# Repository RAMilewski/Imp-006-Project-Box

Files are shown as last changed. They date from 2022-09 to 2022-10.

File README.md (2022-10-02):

# Imp-006-Project-Box
Modular box for Electric Imp 006 breakout board and add-ons.

The Imp006 breakout board offers world-class security and ubiquitous connectivity, including cellular data starting at $3 per month that can be turned off and on again to avoid connectivity charges.  It has GPS, Glonass, Galileo, Beidu/Compass, & QZSS positioning, as well as dual-band WiFi, and BLE networking.  i2c, Mikro Bus and 8 UART connections are available as well as a GPIO connector. See https://www.electricimp.com/imp006-breakout/ for full documentation.

There are two different box lids available.  The two-piece lid that involves a color change, or a one-piece blank lid. All of the provided STLs print without supports. Proper rendering of the logo panel requires Comfortaa Bold a free Google typeface, and two Avenir fonts, Avenir Black Oblique and Next Condensed Heavy, both of which are available from multiple free online sources. Avenir Next Condensed Heavy is also used for the GNSS antenna holder.

The box design acommodates the use of “mezzanine” expansion layers that stack between the box and the lid.  A mezzanine layer with prototyping breadboards is forthcoming.

The OpenSCAD file requires the BOSL2 library, see https://github.com/revarbat/BOSL2. Full BOSL2 documentiation with copius examples is at https://github.com/revarbat/BOSL2/wiki. 

The OpenSCAD file can render all of the STLs with the Customizer allowing custom tweaks.

The Antenna Plate STL is included to allow mounting the adhesive-backed cellular antenna, although use of the part is optional.  You can simply slip the antenna with the adhesive backing paper attached into the antenna slot in the box.  I don't recommend sticking the antenna to the box as that makes moving the antenna to a different (improved?) box in the future more difficult.

 Version 2.4 Update

 Raised the pcb to accomodate the Twilio recommended 3.7v 2000ma battery (Adafruit product ID 2011).  See the Electric Imp documentation for jumper setting details to enable the on-board battery charger. IMPORTANT: Before substituting similar batteries from other sources, double check the polarity at the battery's JST connector.

 Made minor adjustments to the position of the grove and USB connector holes improve the fit of the board.

 Repositioned the GNSS antenna to clear Mikro Click sensor boards. See https://www.mikroe.com/click for more than a thousand Click boards, including 450 sensor boards.

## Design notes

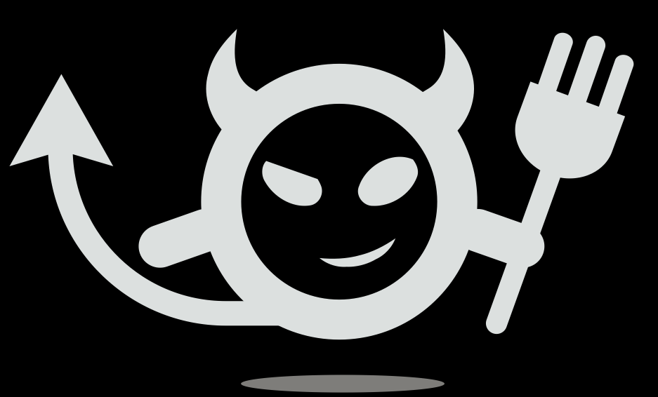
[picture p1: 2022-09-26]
Images/The Dude.png

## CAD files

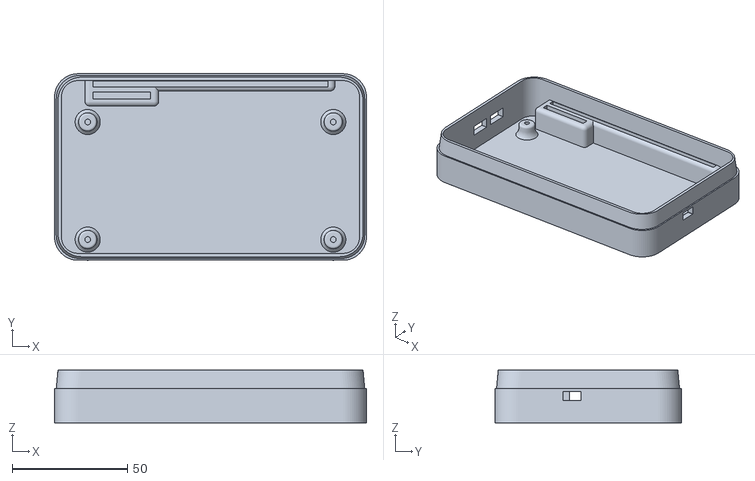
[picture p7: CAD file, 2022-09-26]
006 STLs/2.3 STLs/box.stl
135.5 x 81.0 x 23.0

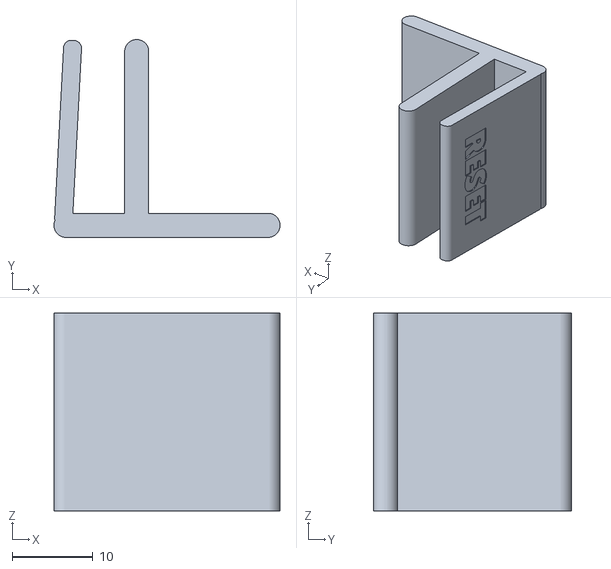
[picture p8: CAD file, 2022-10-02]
006 STLs/2.4 STLs/gnss_2.4.stl
28.0 x 24.5 x 24.5

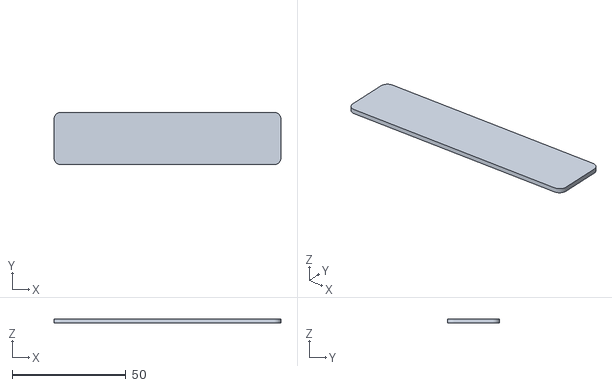
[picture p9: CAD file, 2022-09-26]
006 STLs/2.3 STLs/antenna_plate.stl
100.0 x 23.0 x 1.75

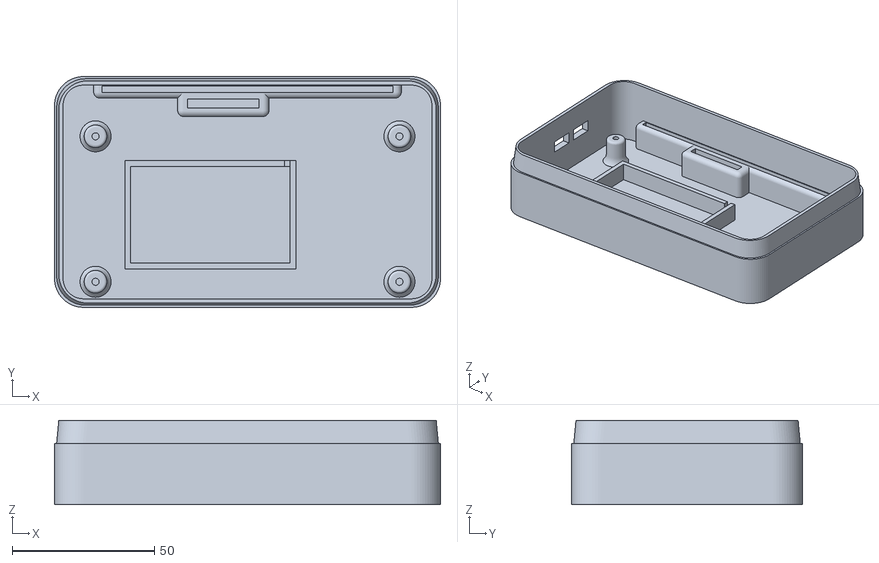
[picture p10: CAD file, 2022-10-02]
006 STLs/2.4 STLs/box_2.4.stl
135.5 x 81.0 x 29.5

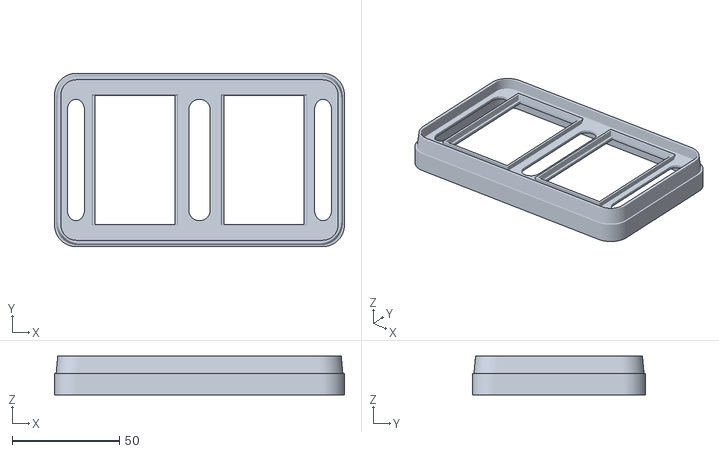
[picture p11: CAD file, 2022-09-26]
006 STLs/2.3 STLs/breadboard.stl
135.5 x 81.0 x 18.0

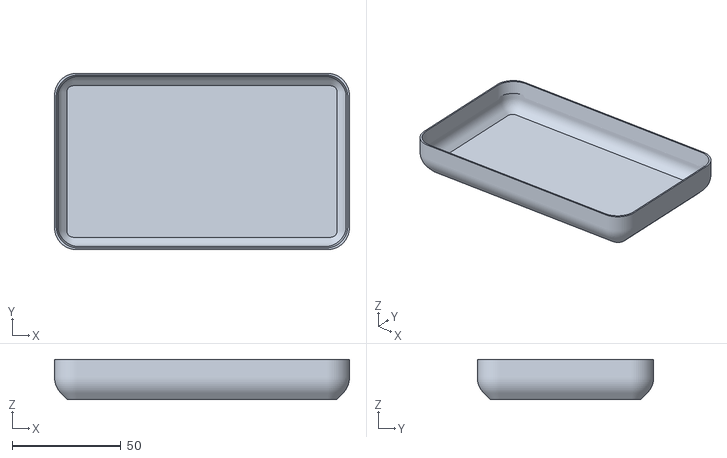
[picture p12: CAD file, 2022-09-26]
006 STLs/2.4 STLs/lid_blank_2.4.stl
135.5 x 81.0 x 18.5

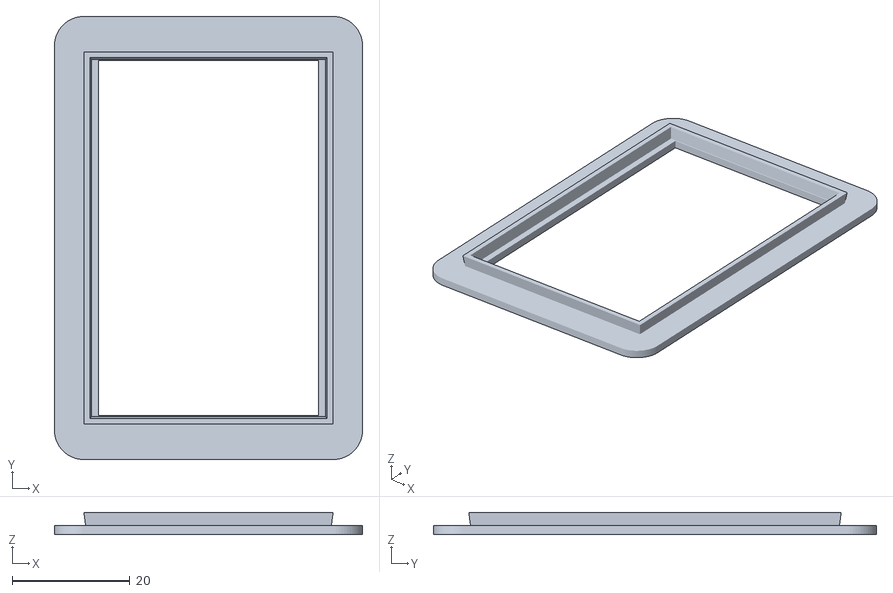
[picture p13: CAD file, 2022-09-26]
006 STLs/2.3 STLs/breadboard_test.stl
52.3 x 75.2 x 3.75

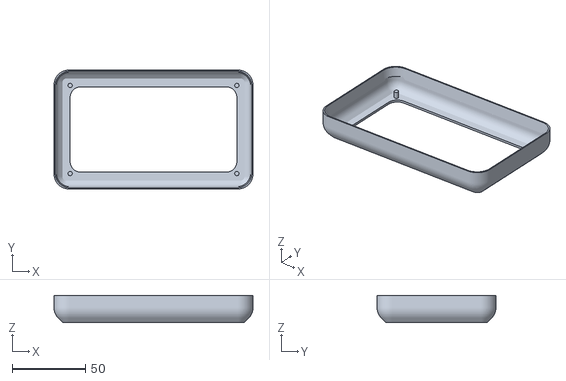
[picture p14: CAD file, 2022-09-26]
006 STLs/2.4 STLs/lid_logo_2.4.stl
135.5 x 81.0 x 18.5

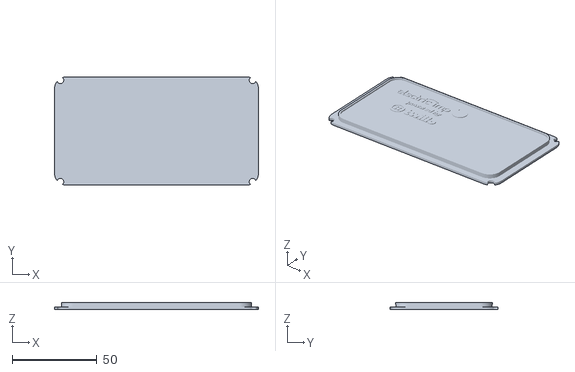
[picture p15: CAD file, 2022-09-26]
006 STLs/2.3 STLs/logo.stl
120.5 x 64.0 x 4.00

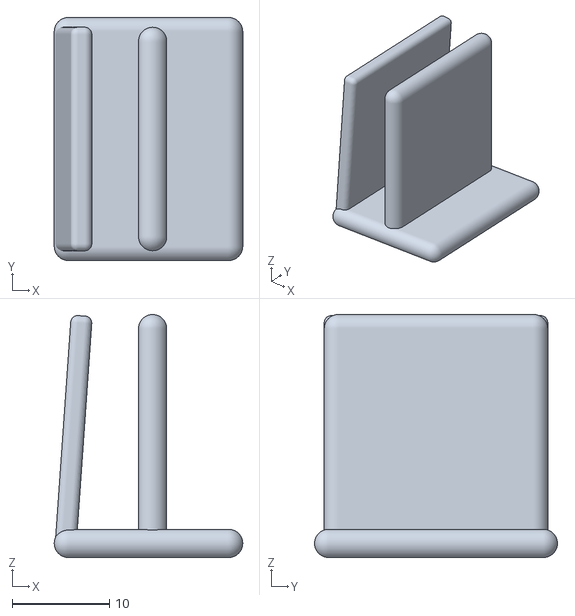
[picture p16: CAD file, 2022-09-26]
006 STLs/2.3 STLs/gnss.stl
19.4 x 25.0 x 25.0

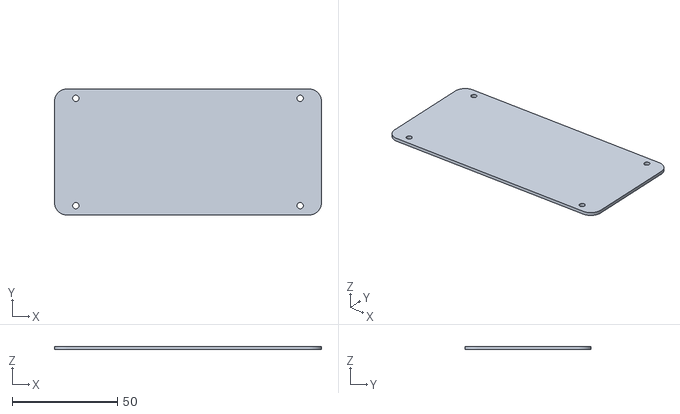
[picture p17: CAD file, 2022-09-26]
006 STLs/2.3 STLs/pcb.stl
127.0 x 60.0 x 1.60

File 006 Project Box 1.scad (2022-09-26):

/*#################################################################################*\
   006 Project Box 1.scad
	-----------------------------------------------------------------------------

	Developed by:			Richard A. Milewski
	Description:            Project Box for Electric Imp 006 Breakout Board
   	
	Version:                1.0
	Creation Date:          30 July 2022
	Modification Date:      
	Email:                  richard+scad@milewski.org
	Copyright				©2022 by Richard A. Milewski
    License - CC-BY-NC      https://creativecommons.org/licenses/by-nc/3.0/ 

\*#################################################################################*/


/*#################################################################################*\
    
    Notes

	Measurements labeled <NEC> are from the New Age Enclosures PDF spec sheet.
	Dimensions labelens <Measured> are from an Imp 006 Breakout Board rev 4.0.
    The Origin of the coördinates is the XY center of the board.
\*#################################################################################*/


/*#################################################################################*\
    
    CONFIGURATION

\*#################################################################################*/
include <BOSL2/std.scad>

// The part you wish to print
part = "top";		//	[box, top, logo, antenna, GNSS, pallet, test]      


// Wall hole selectors	
use_usb = true;		// [true, false]	
use_grove = true;	// [true, false]	

// Logo on top?
use_logo = true;	// true prints a 2 piece top, false prints a single piece top

// Set to false before rendering stl.
show_pcb = false;      // [true, false]

module hidevars () {}  	// variables below hidden from Customizer


$fn = 64;


pcb      = [127, 60, 1.6];						            // <Measured>
pcb2     = [2.5 * INCH * 2, 1.28 * INCH * 2, 0.062 * INCH]; // <NEC> Mythical PCB prototype.
offset   = [0,-12,5];	
mount_hole_dwg = [-.120 * INCH, undef, 0.062 * INCH];		// Mounting hole from <NEC> PDF. 	
mount   = [2.1 * INCH, 1.005 * INCH];			            // Mounting hole positions from <NEC> PCB

mount_spacing = [mount.x * 2, mount.y * 2];
mount_stud = [6, undef, offset.z];
mount_hole = [3, undef, 6];

corner  = 0.4 * INCH; 							
icorner = corner * 0.6;		// A judgment call, seems to look ok.

box_wall = 3;
box = [pcb.x + abs(offset.x) + 3 * box_wall, pcb.y + abs(offset.y) + 3 * box_wall, 27];
wall_position = [box.x/2-box_wall/2, box.y/2-box_wall/2];
pcb_edge = [offset.x + pcb.x/2, offset.y + pcb.y/2, offset.z + pcb.z + box_wall];

top = [box.x, box.y, 8];
top_pin = [5, undef, box_wall + 5];
top_pin_spacing = [top.x - 20, top.y - 20];

deck = [box.x - 3 * box_wall, box.y - 3 * box_wall, 2];
logo_cutout = [box.x-25, box.y-25, box_wall];
logo_border = 2;

stacker_taper = 0.75 * box_wall;
stacker_edge = 0.5;
stacker = [undef, undef, 5];	// Height of the mating surface atop the box.

antenna_plate = [100, 23, 1.75];
antenna_mount = [108, 6, antenna_plate.y*0.5];
antenna_slot  = [102, 3, antenna_mount.z+1];
antenna_mount_position = [0, wall_position.y-antenna_mount.y/2, box_wall];
antenna_slot_position  = [0, box.y/2 - 1.5 * box_wall, box_wall];

gnss_mount = [32, 11, antenna_mount.z];
gnss_slot = [25, 3, antenna_mount.z+1];
gnss_slot_position = [-antenna_slot.x/2 + gnss_slot.x/2, antenna_slot_position.y - 5, box_wall];
gnss_mount_position = [-antenna_slot.x/2 + gnss_slot.x/2,wall_position.y-gnss_mount.y/2,box_wall];


// Holes in the box walls -- Fixed numbers are <Measured>

grove 	  		= [2*box_wall, 10, 5];
grove_spacing	=  grove.y + 3;
grove_position1	= [-wall_position.x - box_wall/2, -7.5 + offset.y , pcb_edge.z];
grove_position2	= [grove_position1.x, grove_position1.y + grove_spacing, grove_position1.z];
led_window	  	= [box_wall * 0.75, 4, 4]; 
led_window_position	= [wall_position.x - box_wall/2, 3.4 + offset.y, pcb_edge.z];
usb 	  		= [2*box_wall, 8, 4];
usb_position	= [wall_position.x - box_wall/2, -10 + offset.y,  pcb_edge.z];

/*#################################################################################*\
    
    Main

\*#################################################################################*/

if (part == "antenna") 	antenna();	// Mounting plate for antenna.
if (part == "box") 		box();		// Box Bottom.
if (part == "top") 	{	*top();		// Top with Logo Cutout
				up(15) logo(); }

// Related objects
if (part == "pallet") 	pallet();	// Temporary desktop platform for the breakout board.

// Test Prints
// Clipped parts of the box to test wall hole locations 
if (part == "grove_end") 	test_1("grove");		// Grove Connector Partial End Piece
if (part == "usb_end") 		test_1("usb");	// USB Connector Partial End Piece

// Utility test choice - change the function below to execute temporary modules
if (part == "test") 	back_half(s=200) logo();	// Temp Misc Tests

/*#################################################################################*\
    
	rounding = iround, edges = "Z", anchor = BOT;
    Modules

\*#################################################################################*/

module box() {
	color("slategray")   base();
	color("goldenrod")   antenna_mounts();
	color("yellow")      walls();
	color("lime")        stud_set();
	color("deepskyblue") dummy_pcb();
	color("magenta")     up(box.z) stacker();
}
	

module base () {	//the bottom of the box 
	cuboid ([box.x, box.y, box_wall], 
	rounding = corner, edges = "Z", anchor = BOT); 
}
module antenna_mounts(){
	difference() {
		union() {
			move(antenna_mount_position)
				cuboid(antenna_mount, rounding = 2, edges = [TOP,FRONT], except = [BOT,BACK], anchor = BOT); 
			move(gnss_mount_position) 
				cuboid(gnss_mount, rounding = 2, edges = [TOP,FRONT], except = [BOT,BACK], anchor = BOT); 	
		}
		union() {
			move(antenna_slot_position)
				cuboid(antenna_slot, anchor = BOT);
			move(gnss_slot_position)
			cuboid(gnss_slot, anchor = BOT);
		}
	}
}

module walls() {
	//difference() {
		rect_tube (size = [box.x, box.y], wall = box_wall, h = box.z, 
			rounding = corner, irounding = icorner, anchor = BOT);
		union() {
			move(led_window_position) color("blue") cuboid(led_window, rounding = 1, edges = "X", anchor = BOT);
			if (use_grove) {   
				move(grove_position1)  cuboid(grove, anchor = BOT);
				move(grove_position2)  cuboid(grove, anchor = BOT);
			}
			if (use_usb) move(usb_position) color("red") cuboid(usb, rounding = 0.2, anchor = BOT);
		//}
	}
}

module stud() {   // A single mounting stud.
	difference() {
			cyl(h = mount_stud.z, d = mount_stud.x, anchor = BOT);	
			down(box_wall/2) cyl(h = mount_stud.z + mount_hole.z, d = mount_hole.x, anchor = BOT);
	}
}

module stud_set() { 
	move(offset/2)
	grid2d(size = mount_spacing, spacing = mount_spacing) stud(); 
	}

module dummy_pcb() { 
	if (show_pcb) {
		move([offset.x/2, offset.y/2, offset.z * 1.5]) {  
			difference () { 
				cuboid(pcb, rounding = 6, edges = "Z", anchor = BOT); 
				grid2d(size = mount_spacing, spacing = mount_spacing) cyl(h = mount_hole.z, d = mount_hole.x);
			}
		}
	}
}

module stacker() {	// Top iterface ring to stack box 
					// yrot(180) and use as a mask for bottom interfaces 		

		A = [box.x - stacker_edge, box.y - stacker_edge];
		B = [box.x - stacker_taper - stacker_edge, box.y - stacker_taper - stacker_edge];
		C = [box.x - 2 * box_wall, box.y - 2 * box_wall];
		rect_tube ( size1 = A, size2 = B, isize = C,
			h=stacker.z, rounding = corner, irounding = icorner);
}

module top() {
	if (logo) {
		logo_deck();
	} else {
		plain_deck();
	}
	top_walls ();
}

module plain_deck () {
	cuboid ([box.x, box.y, deck.z], 	
		rounding = corner, edges = "Z", anchor = BOT);
}

module logo_deck  () {		
	difference () {
		cuboid ([box.x, box.y, deck.z], 	
			rounding = corner, edges = "Z", anchor = BOT);	
		cuboid ([logo_cutout], 	
			rounding = corner, edges = "Z", anchor = BOT); 
	}
	grid2d(size = top_pin_spacing, spacing = top_pin_spacing) 
	color("red") cyl(h = top_pin.z, d = top_pin.x, anchor = BOT); 
}


module top_walls() {
	difference() {
		rect_tube (size = [top.x, top.y], wall = box_wall, h = top.z, 
			rounding = corner, irounding = icorner, anchor = BOT);
		up (top.z) yrot (180) stacker();
	}
}

module logo() {
	difference() {
		cuboid( deck, rounding = icorner, edges = "Z", anchor = BOT);
		grid2d(size = top_pin_spacing, spacing = top_pin_spacing) 
			color("red") cyl(h = deck.z + 1, d = top_pin.x + 1, anchor = BOT); 
	}
	up(1) cuboid (logo_cutout, 	
			rounding = icorner, edges = "Z", anchor = BOT);
	up(4) color("skyblue") rect_tube (size = [logo_cutout.x, logo_cutout.y], h = box_wall, wall = logo_border, 	
			rounding = icorner, anchor = BOT); 
}

//Loose Parts

module antenna() { cuboid (antenna_plate, edges = "Z", rounding = 3); }   // Cellular antenna plate

module lens() { cuboid(lens, anchor = LEFT); }
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

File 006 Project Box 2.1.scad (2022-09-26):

/*#################################################################################*\
   006 Project Box.scad
	-----------------------------------------------------------------------------
	Developed by:			Richard A. Milewski
	Description:            Project Box for Electric Imp 006 Breakout Board
   	
	Version:                2.1
	Creation Date:          30 July 2022
	Modification Date:      24 Aug 2022
	Email:                  richard+scad@milewski.org
	Copyright				©2022 by Richard A. Milewski
    License - CC-BY-NC      https://creativecommons.org/licenses/by-nc/3.0/ 

##################################################################################\
		CONFIGURATION
#################################################################################*/

/*	Measurements labeled <NEC> are from the New Age Enclosures spec sheet pdf.
	Dimensions labeled <Measured> are from an Imp 006 Breakout Board rev 4.0.
	The Origin of the coördinate space is the XY center of the board.
	The USB connector overhangs the edge of the rev 4.0 PCB by 1.5 mm.
*/
include <BOSL2/std.scad>
include <imp006_logos.scad>


// The part you wish to print
part = "breadboard";		//	[antenna, box, gnss, lid, logo, breadboard]      


// Wall hole selectors	
use_usb = true;		// [true, false]	
use_grove = true;	// [true, false]	

// Logo on top deck?
use_logo = true;	// true prints a top with a cut-out for a logo plate, 
					// false prints a blank top

// Set to false before rendering stl.
show_pcb = false;      // [true, false]

$slop = 0.1;			// printer dependant clearance for nested parts.

module hidevars () {}  	// variables below hidden from Customizer

$fn = 64;

pcb_NEC = [2.5 * INCH * 2, 1.28 * INCH * 2, 0.062 * INCH];	// <NEC> Mythical PCB prototype.
pcb	= [127, 60, 1.6];	 						            // <Measured>

box_shift = [0,6,0];	// Move the box, but keep the board centered on the origin.
box_wall = 3;
usb_offset = use_usb ? 0 : 2; 
box = [pcb.x + 8.5 + usb_offset , pcb.y + 21, 15]; 
// Note: box.z is only the height of the lower box, 
//		 it does not include lid.z or stacker.z. 
wall_iedge = [box.x/2-box_wall/2, box.y/2-box_wall/2];
pcb_lift = 5;			// To enable mounting screws 
pcb_edge = [pcb.x/2, pcb.y/2, pcb_lift + pcb.z + box_wall];
base = [box.x, box.y, box_wall/2];

pcb_mount_hole_dwg = [-.120 * INCH, undef, 0.062 * INCH];	// Mounting hole from <NEC> PDF. 	
pcb_mount = [2.1 * INCH, 1.005 * INCH];			            // Mounting hole positions from <NEC> pdf
pcb_mount_spacing = [pcb_mount.x * 2, pcb_mount.y * 2];
pcb_mount_stud = [11, 6, pcb_lift + box_wall];
pcb_mount_hole = [2.5, undef, 6];

corner  = 0.4 * INCH; 	// radius of pcb corner  10.16mm				
icorner = corner - box_wall;		
top = [box.x, box.y, 8];
top_pin = [3, undef, box_wall + 3];
top_pin_spread = [top.x - 22, top.y - 21];
top_pin_spacing = [top_pin_spread];

stacker_taper = 0.75 * box_wall;
stacker_edge = 0.5;
stacker = [box.x, box.y, 8];	// Height of the mating surface atop the box.

curve_comp = [7,6];   	// Shrink deck to compensate for rounding curve in the lid.
logo_cutout = [box.x-23, box.y-24, box_wall];
deck = [logo_cutout.x + 8, logo_cutout.y + 7, 1];
logo_border = 2;
logo_z = 0.5;  //height of the logo in the contrastng color
logo_position = [-deck.x*0.18, deck.y*0.16, logo_cutout.z];
lid_size = [box.x, box.y, corner + stacker.z * 0.55];
lid_mask = [lid_size.x - box_wall, lid_size.y - box_wall, lid_size.z];

echo2([box-logo_cutout, logo_cutout, top_pin_spread]);

antenna_plate = [100, 23, 1.75];
antenna_mount = [108, 6, antenna_plate.y*0.5];
antenna_slot  = [102, 2.5, antenna_mount.z+1];
antenna_slot_position  = [0, box.y/2 - 1.5 * box_wall, base.z];
antenna_mount_position = [0, wall_iedge.y - antenna_mount.y/2, base.z];

gnss = [25,25,6.5];
gnss_mount = [32, 11, antenna_mount.z];
gnss_slot = [25, 3, antenna_mount.z+1];
gnss_slot_position = [-antenna_slot.x/2 + gnss_slot.x/2, antenna_slot_position.y - 5, base.z];
gnss_mount_position = [-antenna_slot.x/2 + gnss_slot.x/2,wall_iedge.y - box_wall/2 - gnss_mount.y/2, base.z];
gnss_height = 18;
gnss_cavity_wall = 1.5;

// Holes in the box walls -- Fixed numbers are <Measured>...  or guessed at.

grove 	  		= [box_wall+0.1, 10, 5];
grove_spacing	=  grove.y + 3;
grove_position1	= [-wall_iedge.x,  3 - box_shift.y, pcb_edge.z];
grove_position2	= [grove_position1.x, grove_position1.y + grove_spacing, grove_position1.z];
led_window	  	= [box_wall, 6, 5]; 
led_window_position	= [wall_iedge.x - box_wall/4, 13.4 - box_shift.y - led_window.y/2, pcb_edge.z];
usb 	  		= [box_wall+0.1, 8, 4.2];
usb_position	= [wall_iedge.x, -1 - box_shift.y,  pcb_edge.z];

// Mezzanene Parts

//for breadboard mezzanene
breadboard1 = [40.33, 70.17, 1.6];
cable_hole1 = [10,box.y * 0.7, stacker.z * 2];


/*####   Main   #################################################################*/

if (part == "box") 			box();			// Box Bottom.
if (part == "lid") 			lid();			// Top with optional cutout for logo plate.
if (part == "logo") 		logo_plate();	// Logo Plate
if (part == "antenna") 		antenna();		// Mounting plate for antenna.
if (part == "gnss") 		gnss_holder(); 	// GNSS antenna holder
if (part == "breadboard")	breadboard(); 	// Mezzanine for 2 70x40mm breadboard
			

// Related objects
if (part == "pallet") 	pallet();	// Temporary desktop platform for the breakout board.

// Test Prints
// Clipped parts of the box to test wall hole locations 
if (part == "grove") 	slice("grove");		// Grove Connector Partial End Piece
if (part == "usb") 		slice("usb");	// USB Connector Partial End Piece

// Utility test choice - change the function below to execute temporary modules
if (part == "test") 	add_on_A();	// Temp Misc Tests

/*#################################################################################
/*		Modules		
\*#################################################################################*/

module box() {

	move(box_shift) {
		color_this("skyblue")	base();
		color_this("goldenrod") antenna_mounts();
		color_this("yellow")    walls();
		color_this("magenta")   up(box.z) stacker();
	}
	color_this("lime")        stud_set();
	color_this("deepskyblue") dummy_pcb();
}
	
module base () {	//the bottom of the box 
	cuboid (base, rounding = corner, edges = "Z", anchor = BOT); 
}

module walls() {
	difference() {
		rect_tube (size = [box.x, box.y], wall = box_wall, h = box.z, 
			rounding = corner, irounding = icorner, anchor = BOT);
		union() {
			move(led_window_position) recolor("blue") cuboid(led_window, rounding = 1, edges = "X", anchor = BOT);
			if (use_grove) {   
				move(grove_position1)  cuboid(grove, anchor = BOT);
				move(grove_position2)  cuboid(grove, anchor = BOT);
			}
			if (use_usb) move(usb_position) recolor("red") cuboid(usb, rounding = 0.2, anchor = BOT);
		}
	}
}

module antenna_mounts(){    //Mount points inside the box for antennae 
	difference() {
		union() {
			move(antenna_mount_position)
				cuboid(antenna_mount, rounding = 2, edges = [TOP,FRONT], except = [BOT,BACK], anchor = BOT); 
			move(gnss_mount_position) 
				cuboid(gnss_mount, rounding = 2, edges = [TOP,FRONT], except = [BOT,BACK], anchor = BOT); 	
		}
		union() {
			move(antenna_slot_position)
				cuboid(antenna_slot, anchor = BOT);
			move(gnss_slot_position)
			cuboid(gnss_slot, anchor = BOT);
		}
	}
}

module stud() {   // A single mounting stud.
echo2([pcb_mount_stud]);
	difference() {
			cyl(h = pcb_mount_stud.z, d1 = pcb_mount_stud.x, d2 = pcb_mount_stud.y, anchor = BOT);	
			down(box_wall/2) cyl(h = pcb_mount_stud.z + pcb_mount_hole.z, d = pcb_mount_hole.x, anchor = BOT);
	}
}

module stud_set() { 
	grid2d(size = pcb_mount_spacing, spacing = pcb_mount_spacing) stud(); 
}

module dummy_pcb() { // a blank plate the size and shape of the pc board.
	if (show_pcb) {
		zmove(pcb_lift) {  
			difference () { 
				#cuboid(pcb, rounding = icorner, edges = "Z", anchor = BOT); 
				grid2d(size = pcb_mount_spacing, spacing = pcb_mount_spacing) cyl(h = pcb_mount_hole.z, d = pcb_mount_hole.x);
			}
		}
	}
}

module stacker(is_top) {	// Iterface ring to stack box 

	A = [box.x - stacker_edge, box.y - stacker_edge];
	B = [box.x - stacker_taper - stacker_edge, box.y - stacker_taper - stacker_edge];
	C = [box.x - 2 * box_wall, box.y - 2 * box_wall];
	
	if (is_top) {
		rect_tube ( size1 = A, size2 = B, isize = C,
			h=stacker.z, rounding = corner, irounding = icorner);
	} else {
		difference() {
			rect_tube(size = [stacker.x, stacker.y], wall = box_wall,
				h = stacker.z, rounding = corner, irounding = icorner);				
			rect_tube ( size1 = A, size2 = B, isize = C,
				h=stacker.z, rounding = corner, irounding = icorner);
		}
	}
}
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

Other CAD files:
006 STLs/2.4 STLs/logo_panel_2.4.3mf
006 STLs/2.3 STLs/logo_panel.3mf
006 Project Box 2.2.scad
006 Project Box 2.3.scad
006 Project Box 2.4.scad
006 STLs/2.3 STLs/logo_panel.stl
006 STLs/2.4 STLs/logo_panel_2.4.stl
imp006_logos.scad
stacker_test.scad
test.scad

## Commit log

2022-09-26 Deleted Duplicate File
    [006 Project Box 2.2 bak 9:2.22.scad, 006 Project Box 2.4.scad]
2022-09-26 Initial upload to Github
    [006 Project Box 1.scad, 006 Project Box 2.1.scad, 006 Project Box 2.2.scad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]
2022-09-29 Relocated GNSS Antenns
    Raised pcb.z to accommodate battery,
    Minor changes to wall windows.
    [006 Project Box 2.4.scad, 006 Project Box 2.4.stl, Box 2.4.stl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]
2022-09-29 Update 006 Project Box 2.4.scad
    Adjusted USB window.
    [006 Project Box 2.4.scad]
2022-09-29 Tightened fit for GNSS holder
    [006 Project Box 2.4.scad]
2022-10-02 2.4 Updates
    [006 Project Box 2.4.scad, 006 Project Box 2.4.stl, Box 2.4.stl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]
2022-11-04 Update 006 Project Box 2.4.scad
    Increased headspace
    [006 Project Box 2.4.scad]
2024-03-06 Added .stl files
    [box_2.4.stl, gnss_2.4.stl, test.scad]
